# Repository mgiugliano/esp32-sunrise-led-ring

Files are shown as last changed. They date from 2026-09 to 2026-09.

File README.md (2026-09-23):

# ESP32 Sunrise/Sunset LED Ring

A WS2812B LED ring, driven by an ESP32-C3 Super Mini, that runs a light-effect schedule tied to sunrise and sunset at your location. Provisioned over a Wi-Fi captive portal, updated over the air, and configurable from a small built-in web page.

## Demo

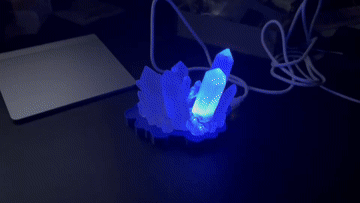
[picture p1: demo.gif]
Demo


## Features

- Wi-Fi captive portal for first-time setup (credentials stored on the device)
- Automatic fallback: if no known network is found at boot, the portal opens again
- Hardware watchdog: reboots automatically if the main loop hangs
- NTP time sync + sunrise/sunset calculation for your location
- Day/night effect rotation (5 presets: Off, Dim glow, Breathe, Rainbow, Comet), configurable per phase from a web page, including rotation speed and movement speed
- Over-the-air (OTA) firmware updates
- Low-power defaults: dim brightness, Wi-Fi modem-sleep, reduced CPU clock during normal operation

## Repository layout

```
firmware/esp32_sunrise_ring/   Arduino sketch -- open esp32_sunrise_ring.ino in the Arduino IDE
tools/led_pin_finder/          Standalone diagnostic sketch to find the ring's data pin
hardware/CrystalRita.3mf       3D-printable enclosure/mount
demo.gif                       Short demo animation
INSTALL.md                     Build, wiring, and flashing instructions
BOM.md                         Full parts list
```

See [INSTALL.md](INSTALL.md) to build one, and [BOM.md](BOM.md) for the parts list.

## Status

Personal/hobby project. Wiring, Wi-Fi provisioning, OTA, the watchdog, and the settings web page have been tested on real hardware. The day/night effects themselves are intentionally simple and are still being refined.

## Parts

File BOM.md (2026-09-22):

# Bill of Materials

| Item | Qty | Notes | Reference |
|---|---|---|---|
| ESP32-C3 Super Mini | 1 | RISC-V, Wi-Fi, USB-C, native USB CDC | SKU `UG152251` |
| WS2812B RGB LED ring, 12 LEDs, 50mm | 1 | Single-wire addressable, 4 pads: 5V / GND / D0 (DI) / D1 (DO) | SKU `6QMK259415` |
| USB-C cable | 1 | For flashing and/or power | any |
| 5V USB power adapter | 1 | e.g. a phone charger; ~500mA is comfortably enough at the default low-brightness settings | any |
| Wiring, 3x | -- | 5V, GND, data -- jumper/Dupont wires or soldered wire | any |
| 3D-printed enclosure/mount | 1 set | see [`hardware/CrystalRita.3mf`](hardware/CrystalRita.3mf) | printed in-house |
| Filament | -- | your choice of color/material | -- |

## Notes

- The two SKU codes above are product/listing reference codes, not personal order numbers -- included so the exact same parts can be sourced again.
- No level shifter is included by default. The ESP32-C3's 3.3V GPIO logic driving the ring's 5V-referenced data line usually works fine over a short wire run; add a level shifter, or a 300-500 ohm series resistor on the data line, only if you see flicker or wrong colors.
- Total cost is low-end hobby-project territory (a few dollars/euros for the board and ring); any generic USB-C cable and 5V/500mA+ adapter works.

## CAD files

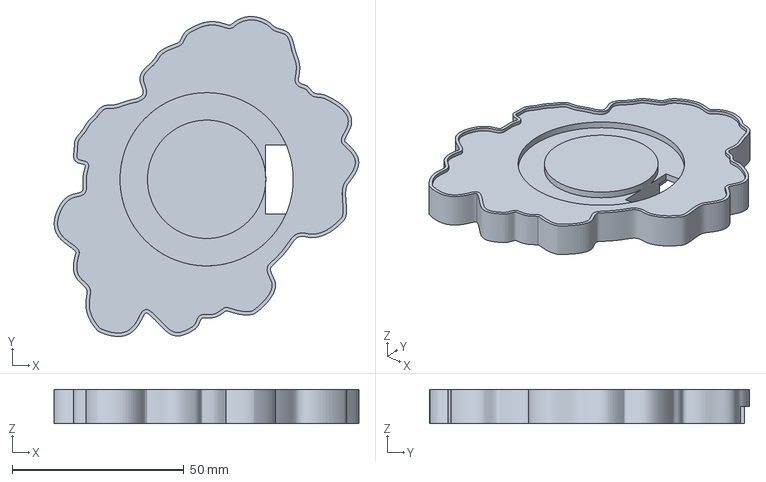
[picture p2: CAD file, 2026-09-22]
hardware/CrystalRita.3mf
88.8 x 93.3 x 10.0 mm

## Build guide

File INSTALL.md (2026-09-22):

# Install & Build Guide

## Hardware needed

See [BOM.md](BOM.md) for the full parts list.

## Wiring

Ring pads: `5V`, `GND`, `D0` (DI, data in), `D1` (DO, data out -- leave unconnected unless daisy-chaining a second ring).

| Ring pad | ESP32-C3 Super Mini pin |
|---|---|
| 5V | 5V |
| GND | GND |
| D0 (DI) | GPIO4 |
| D1 (DO) | not connected |

Pin silkscreen order can vary slightly between board batches/clones -- confirm against your own board's printed labels before wiring. GPIO4 is a safe default; avoid GPIO2/8/9 (strapping pins) and GPIO18/19 (native USB) on the ESP32-C3 Super Mini.

The ESP32-C3's GPIO logic is 3.3V while the ring's data line runs at 5V logic. A short wire (a few cm, as on this compact board) usually works fine without a level shifter. If you see flickering or wrong colors once wired up, add a level shifter or a 300-500 ohm series resistor on the data line.

## Arduino IDE setup

1. Install the `esp32` board package (Espressif Systems), core 3.x, via Boards Manager.
2. Board: "ESP32C3 Dev Module".
3. Tools menu: **USB CDC On Boot = Enabled** -- required for Serial output over the USB-C port. Without this, nothing will ever appear in the Serial Monitor, regardless of what the sketch prints.
4. Tools menu: Partition Scheme = one with two OTA app slots (e.g. "Minimal SPIFFS (1.9MB APP with OTA/190KB SPIFFS)").
5. Library Manager: install `WiFiManager` (tzapu), `Adafruit NeoPixel`, and `Sunset` (buelowp).

## Configure before flashing

Edit `firmware/esp32_sunrise_ring/config.h`:

- `LATITUDE` / `LONGITUDE` / `TZ_INFO` -- set to your install location (defaults to a Rome, Italy placeholder).
- `LED_PIN` -- defaults to GPIO4; change if you wired differently.
- Everything else (AP name, OTA hostname, default brightness, default effect masks) is optional to change.

## First flash

1. Connect via USB-C, select the correct serial port, Upload.
2. Open the Serial Monitor at 115200 baud -- you should see 3 quick red flashes on the ring immediately at boot, followed by diagnostic log lines.
3. If nothing shows in Serial: re-check "USB CDC On Boot = Enabled" (step 3 above), then re-select the port (it can re-enumerate after upload) and reopen the monitor.

## First-time Wi-Fi setup

1. On first boot (no saved credentials), the ring shows a slow amber breathing animation and the device opens a Wi-Fi access point named `LEDring-Setup` (open network, no password).
2. Connect to it from a phone or laptop; a captive portal page should open automatically (or browse to `192.168.4.1`).
3. Choose "Configure WiFi", select your network, enter its password, save.
4. The device reconnects, syncs time over NTP, and starts normal operation. Credentials are saved to flash and reused on every future boot -- if that saved network is ever out of range (e.g. you move the device), it automatically falls back to the portal again on the next power-up.

## Using the web settings page

Once running, browse to `http://esp32-ledring.local/` (or the IP address printed to Serial) from any device on the same network. From there you can:

- See status (current time, sunrise/sunset, uptime, free heap)
- Choose which effects are enabled for day vs. night (Off, Dim glow, Breathe, Rainbow, Comet)
- Set the rotation interval (seconds between pattern switches) and the Comet movement speed
- Trigger a 3x red test flash, to confirm the page is actually reaching the device

Settings are saved to the device's flash (NVS) and survive power cycles.

## Over-the-air (OTA) updates

Once connected, the device advertises itself via mDNS as `esp32-ledring` and should appear under Arduino IDE's Tools -> Port -> Network Ports. Select it and Upload as normal -- no USB cable needed. A password prompt appears regardless of whether one is set in `config.h`; if `OTA_PASSWORD` is left empty (the default), any value you type is accepted since the device doesn't check it.

## Resetting Wi-Fi credentials / all settings

Both Wi-Fi credentials and the effect settings live in the ESP32's flash (NVS), and both survive a normal re-flash. To fully reset either: Arduino IDE -> Tools -> "Erase All Flash Before Sketch Upload" -> Enabled, do one Upload, then set it back to Disabled (otherwise every future flash wipes them again).

## Troubleshooting

- **No Serial output at all**: see "USB CDC On Boot" above -- by far the most common cause on this board, since it has no separate USB-serial chip.
- **OTA device not showing in Network Ports**: a known, long-standing Arduino IDE 2.x bug, not a sketch issue. Try: `ping esp32-ledring.local` from a terminal (confirms mDNS is working, independent of the IDE); fully restart the IDE; wait ~30s after boot before checking; make sure your router isn't isolating Wi-Fi clients from each other (common on guest networks/mesh systems).
- **LEDs don't light up**: use `tools/led_pin_finder/` to sweep candidate GPIOs and visually confirm which one is actually wired to the ring; check 5V/GND continuity with a multimeter with the board powered off.
- **Ring stuck on dim, static blue**: means NTP time hasn't synced yet (no internet reachable on the network). It resumes normal day/night effects automatically once time syncs -- no action needed once internet access returns.

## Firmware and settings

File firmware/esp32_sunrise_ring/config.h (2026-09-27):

#pragma once

// ---- Wi-Fi captive portal ----
#define AP_NAME       "LEDring-Setup"
#define AP_PASSWORD   ""   // "" = open network; if set, must be >= 8 characters (SoftAP requirement)

// ---- Watchdog ----
#define WDT_TIMEOUT_MS   20000UL   // reboot if loop() doesn't feed the watchdog within this long

// ---- Wi-Fi connect timeout ----
// How long wm.autoConnect() may block trying the saved network before giving up and
// falling through to the captive portal. This is a *blocking* call regardless of
// setConfigPortalBlocking(), so it MUST stay comfortably below WDT_TIMEOUT_MS -- otherwise
// an out-of-range saved network causes the watchdog to reboot the device before the
// portal ever gets a chance to start (it never appears, and the device reboot-loops).
#define WIFI_CONNECT_TIMEOUT_SEC  10

// ---- LED ring (AZ-Delivery WS2812B, 12 LEDs, 50 mm) ----
// Ring pads: 5V, GND, D0 (DI, data in) -> wire to LED_PIN, D1 (DO, data out) -> leave unconnected
// unless daisy-chaining a second ring. Avoid GPIO2/8/9 (strapping pins) and GPIO18/19 (native USB)
// on the ESP32-C3 Super Mini.
#define LED_PIN          4
#define LED_COUNT        12
#define LED_BRIGHTNESS   24    // 0-255; kept low for power saving -- effects are designed around this

// ---- Effect cycling (day/night steady-phase preset rotation) ----
// Preset bit positions, shared by night/day masks: 0=Off, 1=Dim glow, 2=Breathe, 3=Rainbow, 4=Comet.
#define DEFAULT_NIGHT_EFFECTS_MASK   0b11110  // Dim glow + Breathe + Rainbow + Comet (Off disabled)
#define DEFAULT_DAY_EFFECTS_MASK     0b00011  // Off + Dim glow
#define DEFAULT_CYCLE_INTERVAL_SEC   600      // seconds between preset switches (10 min); can be set much shorter
#define DEFAULT_MOVEMENT_PERIOD_SEC  8        // seconds per full lap around the ring for movement presets (Comet)

// ---- Location & timezone (EDIT to your install site) ----
#define LATITUDE          41.9028   // placeholder: Rome, Italy -- change to your location
#define LONGITUDE         12.4964
#define UTC_OFFSET_HOURS  1.0       // standard-time UTC offset, no DST (e.g. CET = UTC+1)
#define TZ_INFO           "CET-1CEST,M3.5.0,M10.5.0/3"  // POSIX TZ string; handles DST automatically

// ---- NTP ----
#define NTP_SERVER_1          "pool.ntp.org"
#define NTP_SERVER_2          "time.google.com"
#define NTP_SERVER_3          "time.cloudflare.com"
#define TIME_SYNC_TIMEOUT_MS  30000UL

// ---- OTA ----
#define OTA_HOSTNAME      "esp32-ledring"
#define OTA_PASSWORD      ""   // "" = no password; set one for real deployments

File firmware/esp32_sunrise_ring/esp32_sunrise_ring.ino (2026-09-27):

#include "config.h"
#include "watchdog.h"
#include "wifi_setup.h"
#include "ota_setup.h"
#include "time_sun.h"
#include "led_effects.h"
#include "settings.h"
#include "web_ui.h"

#include <WiFi.h>

enum State {
  STATE_PORTAL_OFFLINE,
  STATE_TIME_SYNC,
  STATE_RUNNING
};

static State state; // zero-initialized -> STATE_PORTAL_OFFLINE
static unsigned long lastHeartbeatMs = 0;

static const char *stateName(State s) {
  switch (s) {
    case STATE_PORTAL_OFFLINE: return "PORTAL_OFFLINE";
    case STATE_TIME_SYNC:      return "TIME_SYNC";
    case STATE_RUNNING:        return "RUNNING";
  }
  return "?";
}

static void setState(State s) {
  Serial.printf("[main] state: %s -> %s\n", stateName(state), stateName(s));
  state = s;
}

void setup() {
  Serial.begin(115200);
  // Give a native-USB CDC port a moment to enumerate so early prints aren't lost
  // if a monitor is already open; harmless (just times out) if nothing is listening.
  unsigned long serialWaitStart = millis();
  while (!Serial && millis() - serialWaitStart < 2000) {
    delay(10);
  }
  delay(200);

  Serial.println();
  Serial.println("=== ESP32-C3 LED ring booting ===");
  Serial.printf("[main] chip=%s freq=%uMHz freeHeap=%u bytes\n",
                 ESP.getChipModel(), ESP.getCpuFreqMHz(), ESP.getFreeHeap());

  watchdogInit(); // first: catches hangs in anything that follows too
  ledInit();
  settingsInit();
  ledBootFlash(); // unconditional "I'm alive" signal, regardless of Wi-Fi state

  Serial.println("[wifi] trying saved credentials...");
  wifiBegin(); // bounded by WIFI_CONNECT_TIMEOUT_SEC; see config.h
  watchdogFeed(); // clear of the one blocking call in setup(); safe to relax here

  if (wifiIsConnected()) {
    WiFi.setSleep(true); // modem-sleep for lower average power
    Serial.printf("[wifi] connected to '%s', IP=%s, RSSI=%ddBm\n",
                   WiFi.SSID().c_str(), WiFi.localIP().toString().c_str(), WiFi.RSSI());
    timeSyncBegin();
    setState(STATE_TIME_SYNC);
  } else {
    setState(STATE_PORTAL_OFFLINE);
  }
}

void loop() {
  watchdogFeed();
  unsigned long nowMs = millis();

  switch (state) {

    case STATE_PORTAL_OFFLINE:
      wifiLoop();
      ledOfflineBreathe(nowMs);
      if (wifiIsConnected()) {
        WiFi.setSleep(true); // modem-sleep for lower average power
        Serial.printf("[wifi] connected to '%s', IP=%s, RSSI=%ddBm\n",
                       WiFi.SSID().c_str(), WiFi.localIP().toString().c_str(), WiFi.RSSI());
        timeSyncBegin();
        setState(STATE_TIME_SYNC);
      }
      break;

    case STATE_TIME_SYNC:
      ledOfflineBreathe(nowMs); // keep some feedback while waiting for NTP
      if (timeSyncCheck()) {
        sunTimesUpdateIfNeeded();
        otaBegin();
        setState(STATE_RUNNING);
      } else if (timeSyncTimedOut()) {
        Serial.println("[time] NTP sync timed out, continuing without it");
        otaBegin();
        setState(STATE_RUNNING);
      }
      break;

    case STATE_RUNNING: {
      static bool runningSetupDone = false;
      if (!runningSetupDone) {
        setCpuFrequencyMhz(80); // steady-state power saving; still plenty for Wi-Fi/OTA/web
        webUiBegin();
        Serial.println("[main] steady-state: CPU scaled to 80MHz, web settings server ready");
        runningSetupDone = true;
      }

      otaLoop();
      webUiLoop();
      sunTimesUpdateIfNeeded();
      int nowMin = currentMinutesOfDay();
      int sunriseMin = sunriseMinutesToday();
      int sunsetMin = sunsetMinutesToday();
      ledUpdate(nowMs, nowMin, sunriseMin, sunsetMin);

      if (nowMs - lastHeartbeatMs > 10000) {
        lastHeartbeatMs = nowMs;
        Serial.printf("[main] heartbeat: uptime=%lus heap=%u RSSI=%ddBm now=%02d:%02d sunrise=%02d:%02d sunset=%02d:%02d\n",
                       nowMs / 1000, ESP.getFreeHeap(), WiFi.RSSI(),
                       nowMin < 0 ? 0 : nowMin / 60, nowMin < 0 ? 0 : nowMin % 60,
                       sunriseMin < 0 ? 0 : sunriseMin / 60, sunriseMin < 0 ? 0 : sunriseMin % 60,
                       sunsetMin < 0 ? 0 : sunsetMin / 60, sunsetMin < 0 ? 0 : sunsetMin % 60);
      }
      break;
    }
  }
}

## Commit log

2026-09-22 Initial commit: ESP32-C3 sunrise/sunset LED ring firmware
    Wi-Fi captive portal provisioning, OTA updates, hardware watchdog,
    NTP-synced sunrise/sunset day/night effect rotation with a web
    settings page, plus a pin-finder diagnostic tool and the enclosure
    3D model.
    Claude-Session: https://claude.ai/code/session_01HkSBwu4CM7Y55uHtTXiE9X
    [CrystalRita.3mf]
2026-09-27 Fix: captive portal never appears when saved Wi-Fi is out of range
    wm.autoConnect()'s initial connect attempt against saved credentials
    is a blocking call with no default limit, even with
    setConfigPortalBlocking(false) (that flag only covers the fallback
    portal itself). Against an out-of-range network, it could run past
    the 15s hardware watchdog timeout, causing a panic-reboot before the
    captive portal ever got a chance to start -- an infinite reboot loop
    that looked like "the portal never appears".
    Fix: bound the connect attempt with wm.setConnectTimeout() to a value
    comfortably under the watchdog timeout, and raise the watchdog
    timeout itself for extra margin.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
    [config.h, esp32_sunrise_ring.ino]
2026-09-27 Fix: Comet effect looks static at slow speeds
    The comet's head position was an integer LED index, so the lit
    pixels/brightness held exactly still for (movementPeriodSeconds /
    LED_COUNT) seconds before jumping to the next LED -- at slow speed
    settings that's many seconds to nearly a minute of no visible change,
    easily read as "not working".
    Switched to a continuous (float) position with a per-pixel circular
    distance-to-head calculation, so brightness fades smoothly every
    frame regardless of how slow the overall lap is.
    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
    [led_effects.cpp]
2026-09-27 Surface the active LED preset on the web settings page
    Exposes ledCurrentPresetName() so the settings page can show which
    steady-phase preset is currently selected, without needing Serial --
    useful for diagnosing rotation/mask issues on a remotely-deployed
    device where a USB data cable isn't available.
    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
    [led_effects.cpp]
2026-09-27 Show live rotation-timer state on the web settings page
    Adds "time since last switch / configured interval" so it's possible
    to directly observe whether the interval setting is actually being
    read and used by the rotation logic, without needing Serial.
    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
2026-09-27 Spell out enabled presets in plain text on the web page
    Adds "Enabled for Night: ..." / "Enabled for Day: ..." lines so the
    current mask is unambiguous, instead of relying on correctly reading
    a row of checkboxes -- makes it trivial to spot a phase with only
    one (or zero) presets enabled, which looks identical to "rotation is
    broken" but isn't.
    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
